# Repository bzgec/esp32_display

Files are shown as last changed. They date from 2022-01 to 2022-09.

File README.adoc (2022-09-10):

= MQTT display HW
:toc:
:sectnums:
:sectnumlevels: 4

* Current version: *0.1*
* link:./CHANGELOG.adoc[Changelog]

'''

MQTT display using:

* ESP32
* ILI9341 display

[link="./Res/pic/display_mqtt.jpg"]
.Example
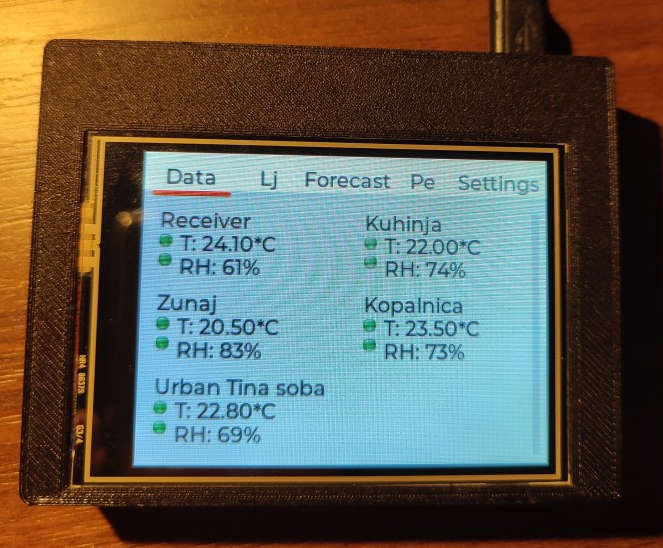
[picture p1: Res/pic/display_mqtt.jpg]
display_mqtt


== PCB:

=== v0.1

[link="./Res/pic/hw_v0.1_bottom_real.jpg"]
.HW v0.1
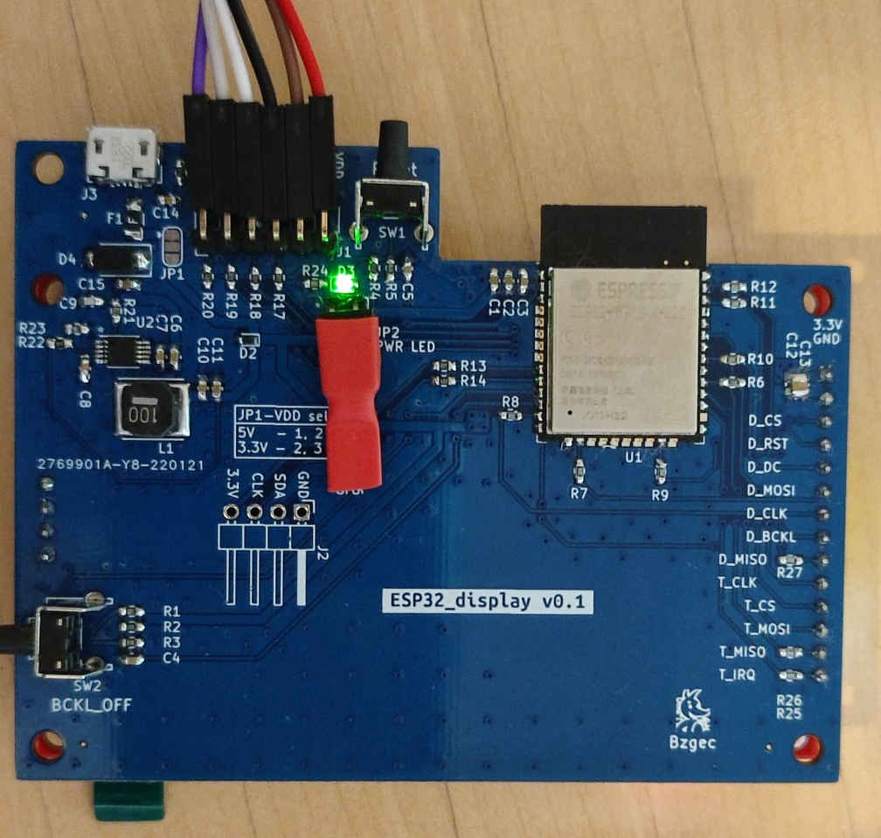
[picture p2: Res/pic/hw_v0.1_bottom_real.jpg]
hw_v0.1_bottom_real


== Automated exporting
=== Installation
==== KiBot
link:https://github.com/INTI-CMNB/kibot#installation-using-pip[Installation]:

* `pip install --no-compile kibot`
(on Windows you probably need to install it in `KiCad Command Prompt`)

* On Arch Linux you can install it with: `paru -S kibot-git`
** You may need to install `pcbdraw-git` in case of
`module 'pcbnew' has no attribute 'PLOTTEXTMODE_STROKE'` error
(try to run `pcbnew --version` to be sure that program runs correctly)
** You also may need to install `imagemagick`: `sudo pacman -S imagemagick`
** You also may need to install few `pip` packages: `pip install mistune pybars3 wand`

==== recordmydesktop
* Needed only if running `kibot -vvv`
* Arch Linux: `sudo pacman -S recordmydesktop`

== TODO
* [ ] Fix silkscreen for programming connector (TX and RX are replaced, also the same for IO0 and RST)
* [ ] Remove Display module SD card slot - that way display can seat lower
  (whole PCB if then thinner)

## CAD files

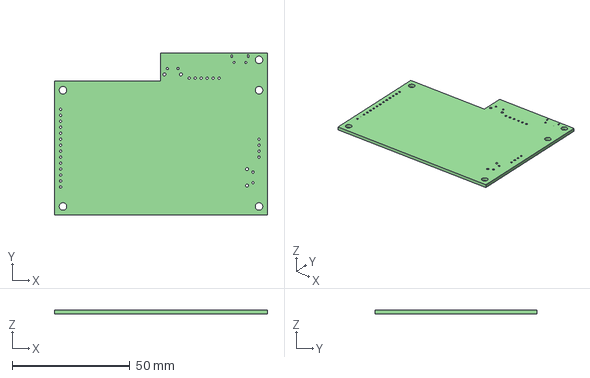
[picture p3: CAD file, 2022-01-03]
Outputs/v0.1/esp32_display.step
90.5 x 69.0 x 1.60 mm

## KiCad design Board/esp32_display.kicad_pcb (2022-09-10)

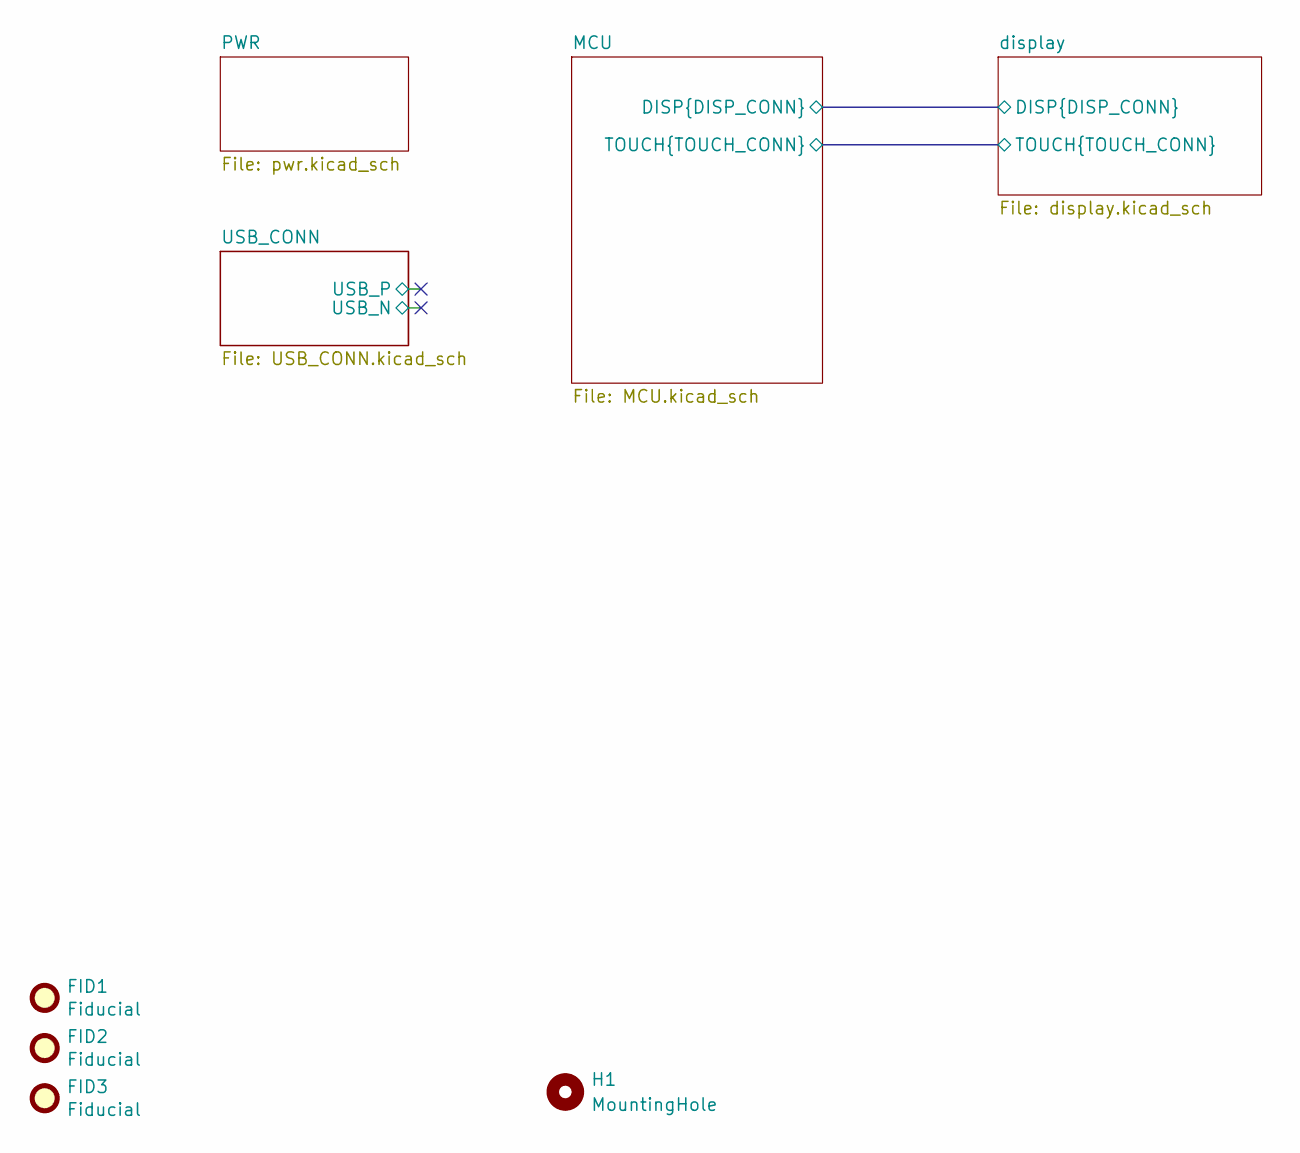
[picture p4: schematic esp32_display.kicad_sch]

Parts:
FID1, FID2, FID3: Fiducial; Fiducial_0.5mm_Mask1mm
H1: MountingHole; MountingHole_3.2mm_M3_ISO14580

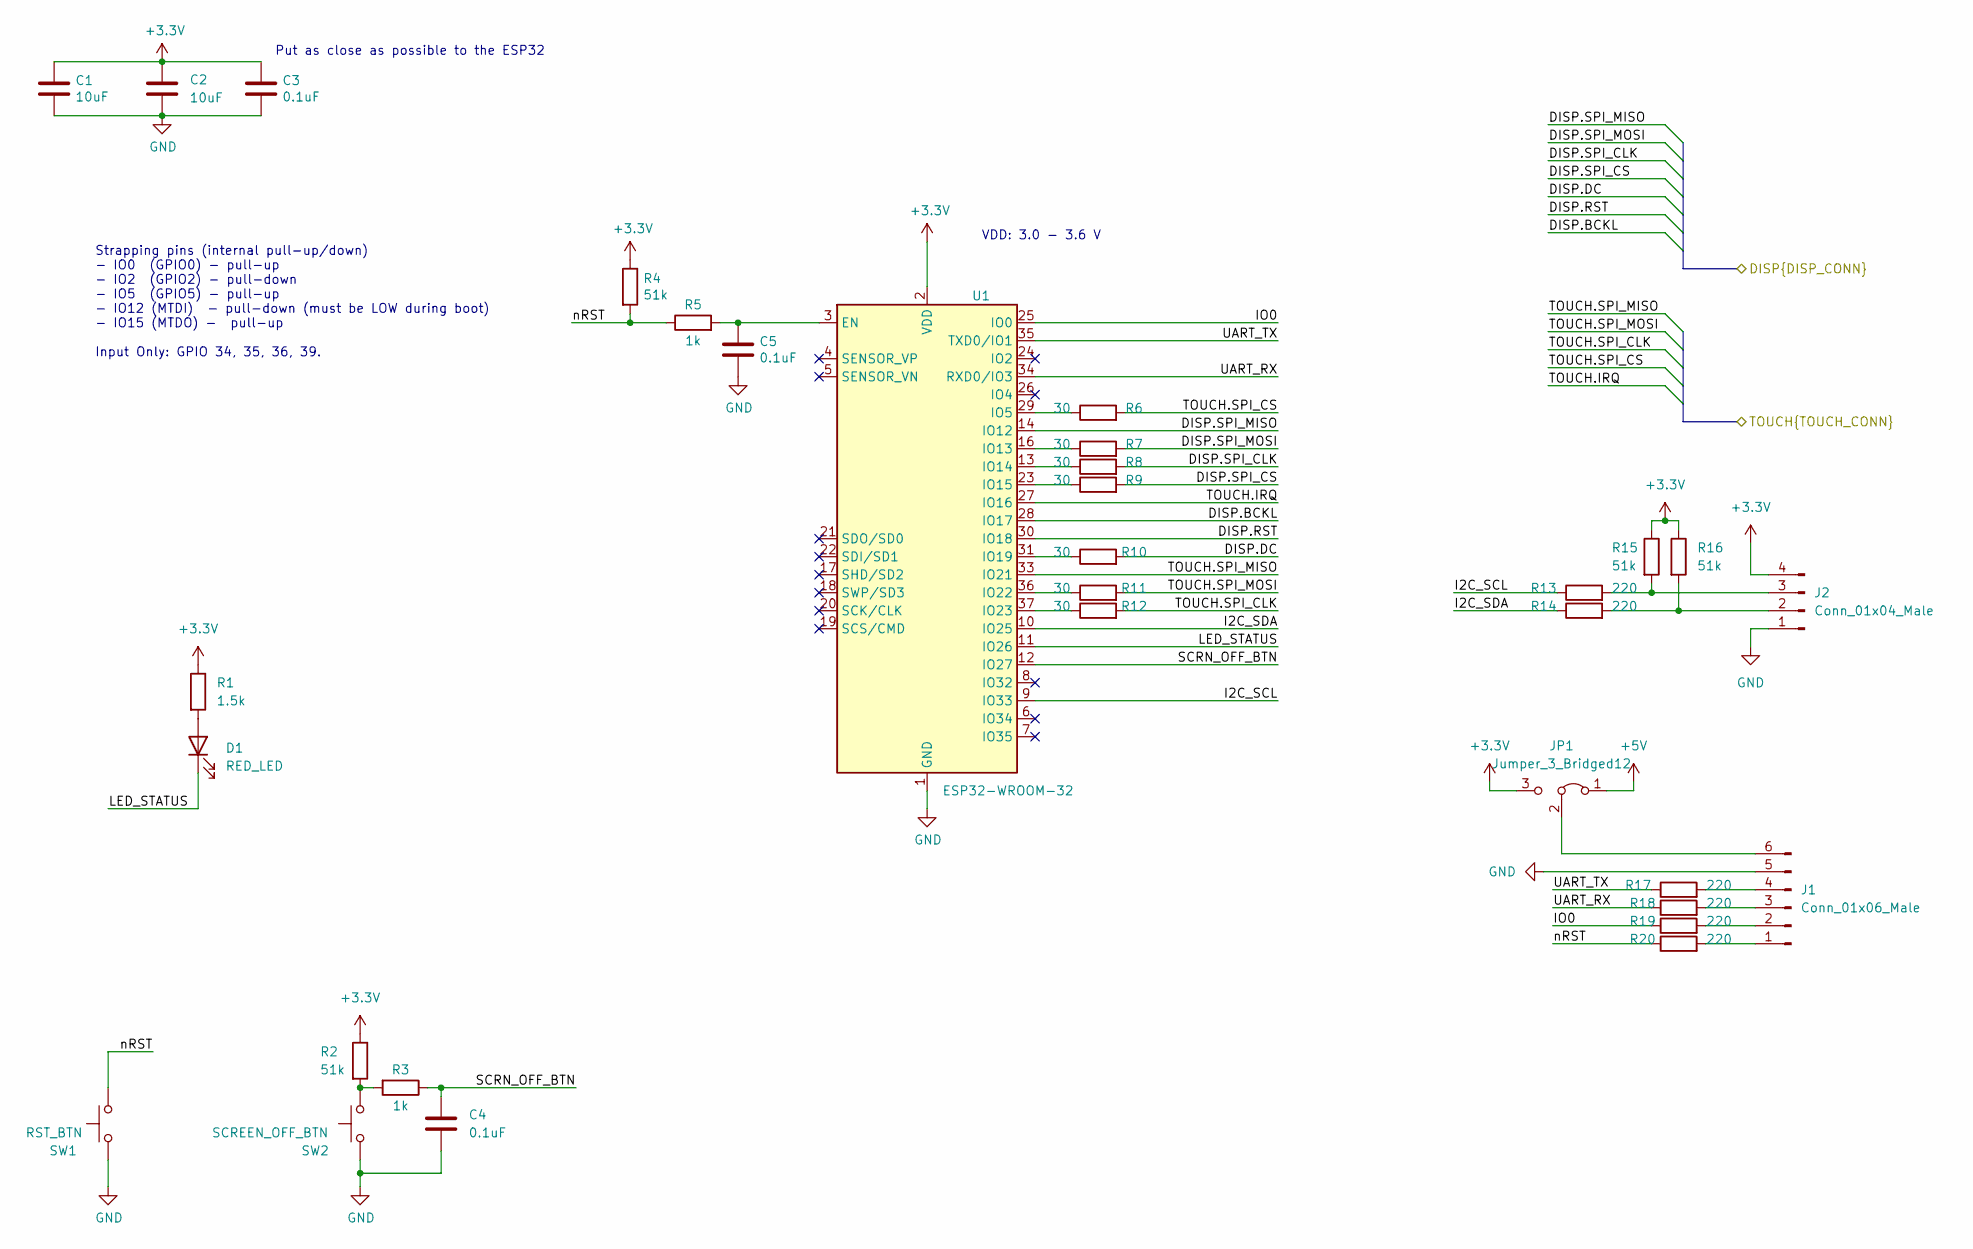
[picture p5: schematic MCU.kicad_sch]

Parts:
C1, C2: 10uF; C_0603_1608Metric_Pad1.08x0.95mm_HandSolder
C3, C4, C5: 0.1uF; C_0603_1608Metric_Pad1.08x0.95mm_HandSolder
D1: RED_LED; D_0603_1608Metric_Pad1.05x0.95mm_HandSolder
J1: Conn_01x06_Male; PinHeader_1x06_P2.54mm_Horizontal
J2: Conn_01x04_Male; PinHeader_1x04_P2.54mm_Horizontal
JP1: Jumper_3_Bridged12; SolderJumper-3_P1.3mm_Bridged12_RoundedPad1.0x1.5mm
R1: 1.5k; R_0603_1608Metric_Pad0.98x0.95mm_HandSolder
R2, R4, R15, R16: 51k; R_0603_1608Metric_Pad0.98x0.95mm_HandSolder
R3, R5: 1k; R_0603_1608Metric_Pad0.98x0.95mm_HandSolder
R6, R7, R8, R9, R10, R11, R12: 30; R_0603_1608Metric_Pad0.98x0.95mm_HandSolder
R13, R14, R17, R18, R19, R20: 220; R_0603_1608Metric_Pad0.98x0.95mm_HandSolder
SW1: RST_BTN; SW_Tactile_SPST_Angled_PTS645Vx83-2LFS
SW2: SCREEN_OFF_BTN; SW_Tactile_SPST_Angled_PTS645Vx83-2LFS
U1: ESP32-WROOM-32

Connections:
+3V3: C1.1, C2.1, C3.1, J2.4, JP1.3 (B), R1.1, R2.1, R4.1, R15.1, R16.1, U1.2 (VDD); also elsewhere on the board
+5V: JP1.1 (A); also elsewhere on the board
/MCU/DISP.BCKL: U1.28 (IO17); also elsewhere on the board
/MCU/DISP.DC: R10.2; also elsewhere on the board
/MCU/DISP.RST: U1.30 (IO18); also elsewhere on the board
/MCU/DISP.SPI_CLK: R8.2; also elsewhere on the board
/MCU/DISP.SPI_CS: R9.2; also elsewhere on the board
/MCU/DISP.SPI_MISO: U1.14 (IO12); also elsewhere on the board
/MCU/DISP.SPI_MOSI: R7.2; also elsewhere on the board
/MCU/I2C_SCL: R13.1, U1.9 (IO33)
/MCU/I2C_SDA: R14.1, U1.10 (IO25)
/MCU/IO0: R19.1, U1.25 (IO0)
/MCU/LED_STATUS: D1.1 (K), U1.11 (IO26)
/MCU/SCRN_OFF_BTN: C4.1, R3.1, U1.12 (IO27)
/MCU/TOUCH.IRQ: U1.27 (IO16); also elsewhere on the board
/MCU/TOUCH.SPI_CLK: R12.2; also elsewhere on the board
/MCU/TOUCH.SPI_CS: R6.2; also elsewhere on the board
/MCU/TOUCH.SPI_MISO: U1.33 (IO21); also elsewhere on the board
/MCU/TOUCH.SPI_MOSI: R11.2; also elsewhere on the board
/MCU/UART_RX: R18.1, U1.34 (RXD0/IO3)
/MCU/UART_TX: R17.1, U1.35 (TXD0/IO1)
/MCU/nRST: R4.2, R5.1, R20.1, SW1.1
GND: C1.2, C2.2, C3.2, C4.2, C5.2, J1.5, J2.1, SW1.2, SW2.2, U1.1 (GND), U1.15 (GND), U1.38 (GND), U1.39 (GND); also elsewhere on the board
unnamed: C5.1, R5.2, U1.3 (EN)
unnamed: D1.2 (A), R1.2
unnamed: J1.1, R20.2
unnamed: J1.2, R19.2
unnamed: J1.3, R18.2
unnamed: J1.4, R17.2
unnamed: J1.6, JP1.2 (C)
unnamed: J2.2, R14.2, R16.2
unnamed: J2.3, R13.2, R15.2
unnamed: R2.2, R3.2, SW2.1
unnamed: R6.1, U1.29 (IO5)
unnamed: R7.1, U1.16 (IO13)
unnamed: R8.1, U1.13 (IO14)
unnamed: R9.1, U1.23 (IO15)
unnamed: R10.1, U1.31 (IO19)
unnamed: R11.1, U1.36 (IO22)
unnamed: R12.1, U1.37 (IO23)

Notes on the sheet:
Put as close as possible to the ESP32
Strapping pins (internal pull-up/down) - IO0 (GPIO0) - pull-up - IO2 (GPIO2) - pull-down - IO5 (GPIO5) - pull-up - IO12 (MTDI) - pull-down (must be LOW during boot) - IO15 (MTDO) - pull-up Input Only: GPIO 34, 35, 36, 39.
VDD: 3.0 - 3.6 V

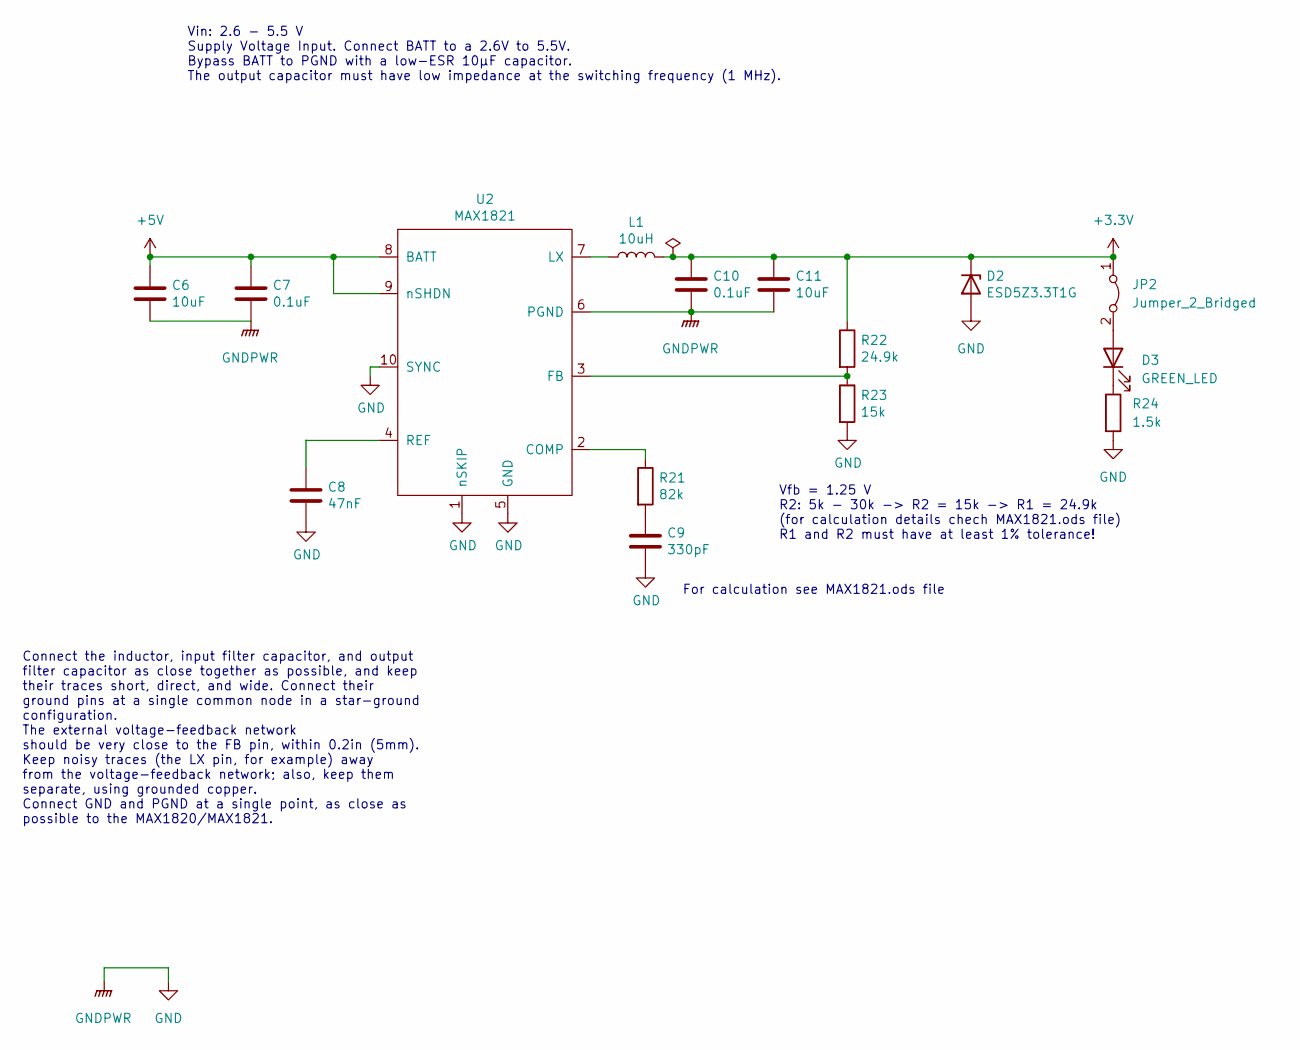
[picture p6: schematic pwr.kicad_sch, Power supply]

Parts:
C6, C11: 10uF; C_0603_1608Metric_Pad1.08x0.95mm_HandSolder
C7, C10: 0.1uF; C_0603_1608Metric_Pad1.08x0.95mm_HandSolder
C8: 47nF; C_0603_1608Metric_Pad1.08x0.95mm_HandSolder
C9: 330pF; C_0603_1608Metric_Pad1.08x0.95mm_HandSolder
D2: ESD5Z3.3T1G; D_SOD-523
D3: GREEN_LED; D_0603_1608Metric_Pad1.05x0.95mm_HandSolder
JP2: Jumper_2_Bridged; PinHeader_1x02_P2.54mm_Horizontal
L1: 10uH; NR6028T100M
R21: 82k; R_0603_1608Metric_Pad0.98x0.95mm_HandSolder
R22: 24.9k; R_0603_1608Metric_Pad0.98x0.95mm_HandSolder
R23: 15k; R_0603_1608Metric_Pad0.98x0.95mm_HandSolder
R24: 1.5k; R_0603_1608Metric_Pad0.98x0.95mm_HandSolder
U2: MAX1821; MAX1821EUB+

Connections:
+3V3: C10.1, C11.1, D2.1 (K), JP2.1 (A), L1.2, R22.1; also elsewhere on the board
+5V: C6.1, C7.1, U2.8 (BATT), U2.9 (nSHDN); also elsewhere on the board
GND: C6.2, C7.2, C8.2, C9.2, C10.2, C11.2, D2.2 (A), R23.2, R24.2, U2.1 (nSKIP), U2.5 (GND), U2.6 (PGND), U2.10 (SYNC); also elsewhere on the board
unnamed: C8.1, U2.4 (REF)
unnamed: C9.1, R21.2
unnamed: D3.1 (K), R24.1
unnamed: D3.2 (A), JP2.2 (B)
unnamed: L1.1, U2.7 (LX)
unnamed: R21.1, U2.2 (COMP)
unnamed: R22.2, R23.1, U2.3 (FB)

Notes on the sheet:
Vfb = 1.25 V R2: 5k - 30k -> R2 = 15k -> R1 = 24.9k (for calculation details chech MAX1821.ods file) R1 and R2 must have at least 1% tolerance!
For calculation see MAX1821.ods file
Connect the inductor, input filter capacitor, and output filter capacitor as close together as possible, and keep their traces short, direct, and wide. Connect their ground pins at a single common node in a star-ground configuration. The external voltage-feedback network should be very close to the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
Vin: 2.6 - 5.5 V Supply Voltage Input. Connect BATT to a 2.6V to 5.5V. Bypass BATT to PGND with a low-ESR 10μF capacitor. The output capacitor must have low impedance at the switching frequency (1 MHz).

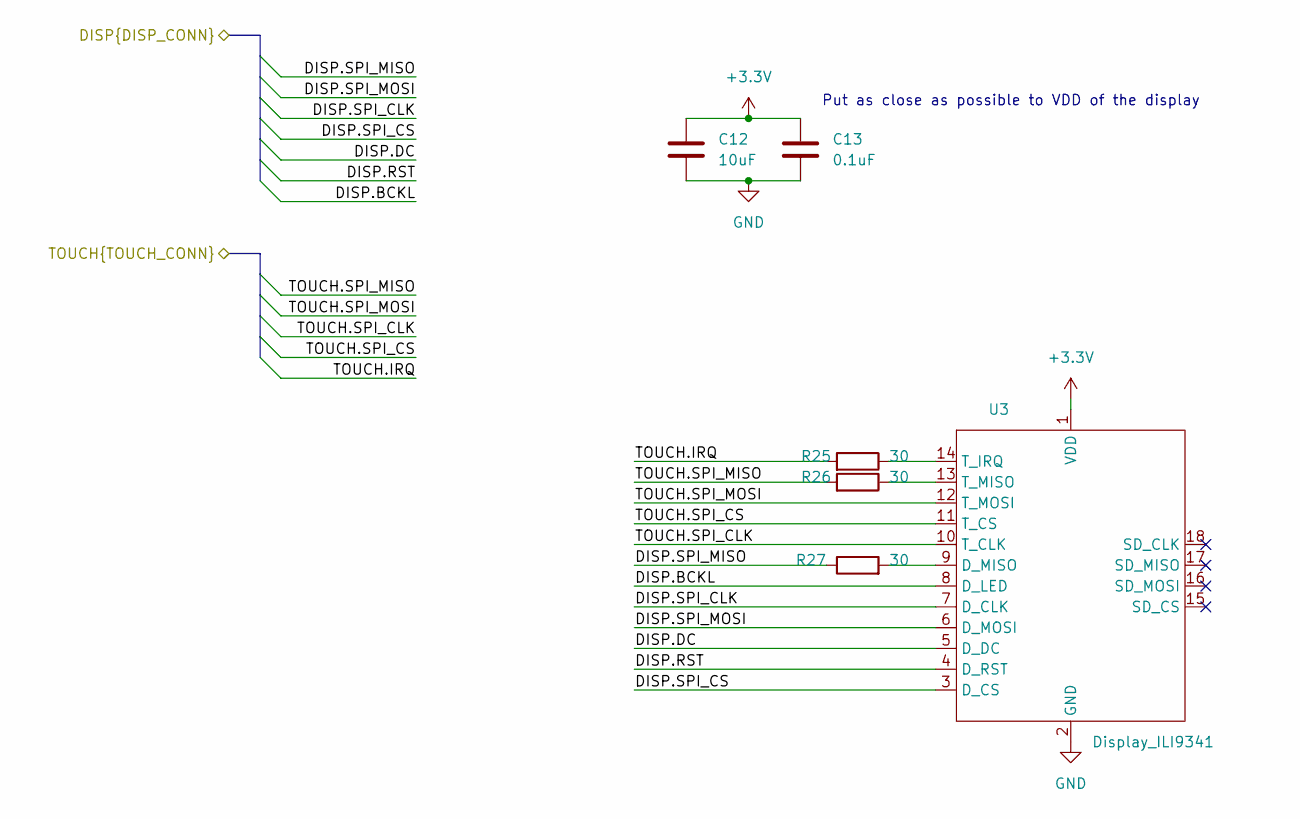
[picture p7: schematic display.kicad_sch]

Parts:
C12: 10uF; C_0603_1608Metric_Pad1.08x0.95mm_HandSolder
C13: 0.1uF; C_0603_1608Metric_Pad1.08x0.95mm_HandSolder
R25, R26, R27: 30; R_0603_1608Metric_Pad0.98x0.95mm_HandSolder
U3: Display_ILI9341; ILI9341

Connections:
+3V3: C12.1, C13.1, U3.1 (VDD); also elsewhere on the board
/MCU/DISP.BCKL: U3.8 (D_LED); also elsewhere on the board
/MCU/DISP.DC: U3.5 (D_DC); also elsewhere on the board
/MCU/DISP.RST: U3.4 (D_RST); also elsewhere on the board
/MCU/DISP.SPI_CLK: U3.7 (D_CLK); also elsewhere on the board
/MCU/DISP.SPI_CS: U3.3 (D_CS); also elsewhere on the board
/MCU/DISP.SPI_MISO: R27.1; also elsewhere on the board
/MCU/DISP.SPI_MOSI: U3.6 (D_MOSI); also elsewhere on the board
/MCU/TOUCH.IRQ: R25.2; also elsewhere on the board
/MCU/TOUCH.SPI_CLK: U3.10 (T_CLK); also elsewhere on the board
/MCU/TOUCH.SPI_CS: U3.11 (T_CS); also elsewhere on the board
/MCU/TOUCH.SPI_MISO: R26.2; also elsewhere on the board
/MCU/TOUCH.SPI_MOSI: U3.12 (T_MOSI); also elsewhere on the board
GND: C12.2, C13.2, U3.2 (GND); also elsewhere on the board
unnamed: R25.1, U3.14 (T_IRQ)
unnamed: R26.1, U3.13 (T_MISO)
unnamed: R27.2, U3.9 (D_MISO)

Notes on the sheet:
Put as close as possible to VDD of the display

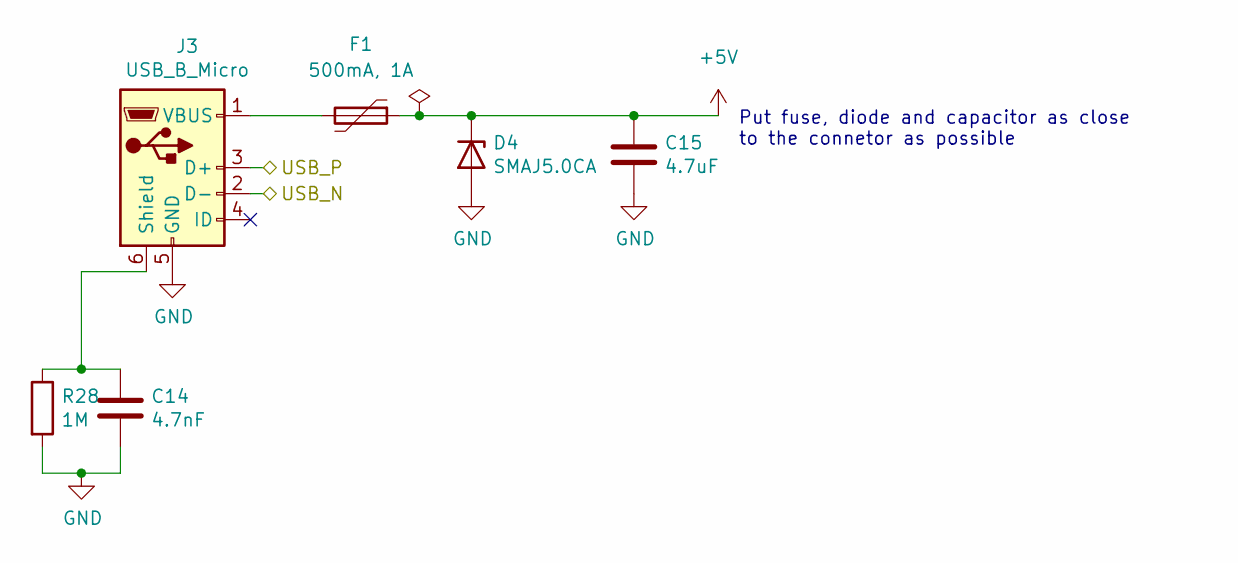
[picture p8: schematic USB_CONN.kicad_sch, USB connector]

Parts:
C14: 4.7nF; C_0603_1608Metric_Pad1.08x0.95mm_HandSolder
C15: 4.7uF; C_0603_1608Metric_Pad1.08x0.95mm_HandSolder
D4: SMAJ5.0CA; D_SMA
F1: 500mA, 1A; Fuse_1206_3216Metric_Pad1.42x1.75mm_HandSolder
J3: USB_B_Micro; USB_Micro-B_Molex-105017-0001
R28: 1M; R_0603_1608Metric_Pad0.98x0.95mm_HandSolder

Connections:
+5V: C15.1, D4.1 (K), F1.1; also elsewhere on the board
/USB_CONN/USB_N: J3.2 (D-)
/USB_CONN/USB_P: J3.3 (D+)
GND: C14.2, C15.2, D4.2 (A), J3.5 (GND), R28.2; also elsewhere on the board
unnamed: C14.1, J3.6 (Shield), R28.1
unnamed: F1.2, J3.1 (VBUS)

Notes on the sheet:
Put fuse, diode and capacitor as close to the connetor as possible

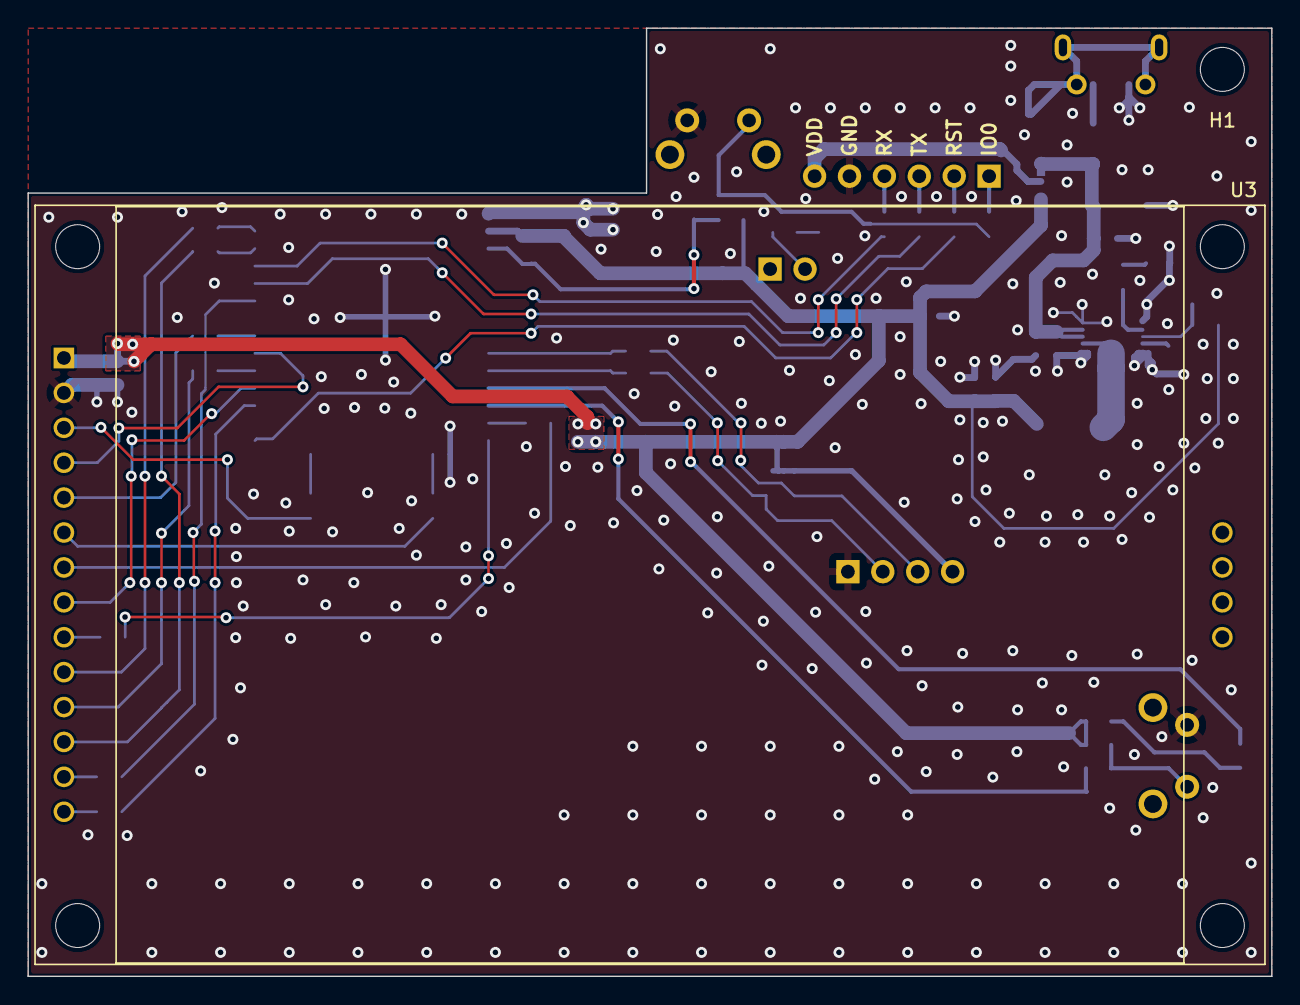
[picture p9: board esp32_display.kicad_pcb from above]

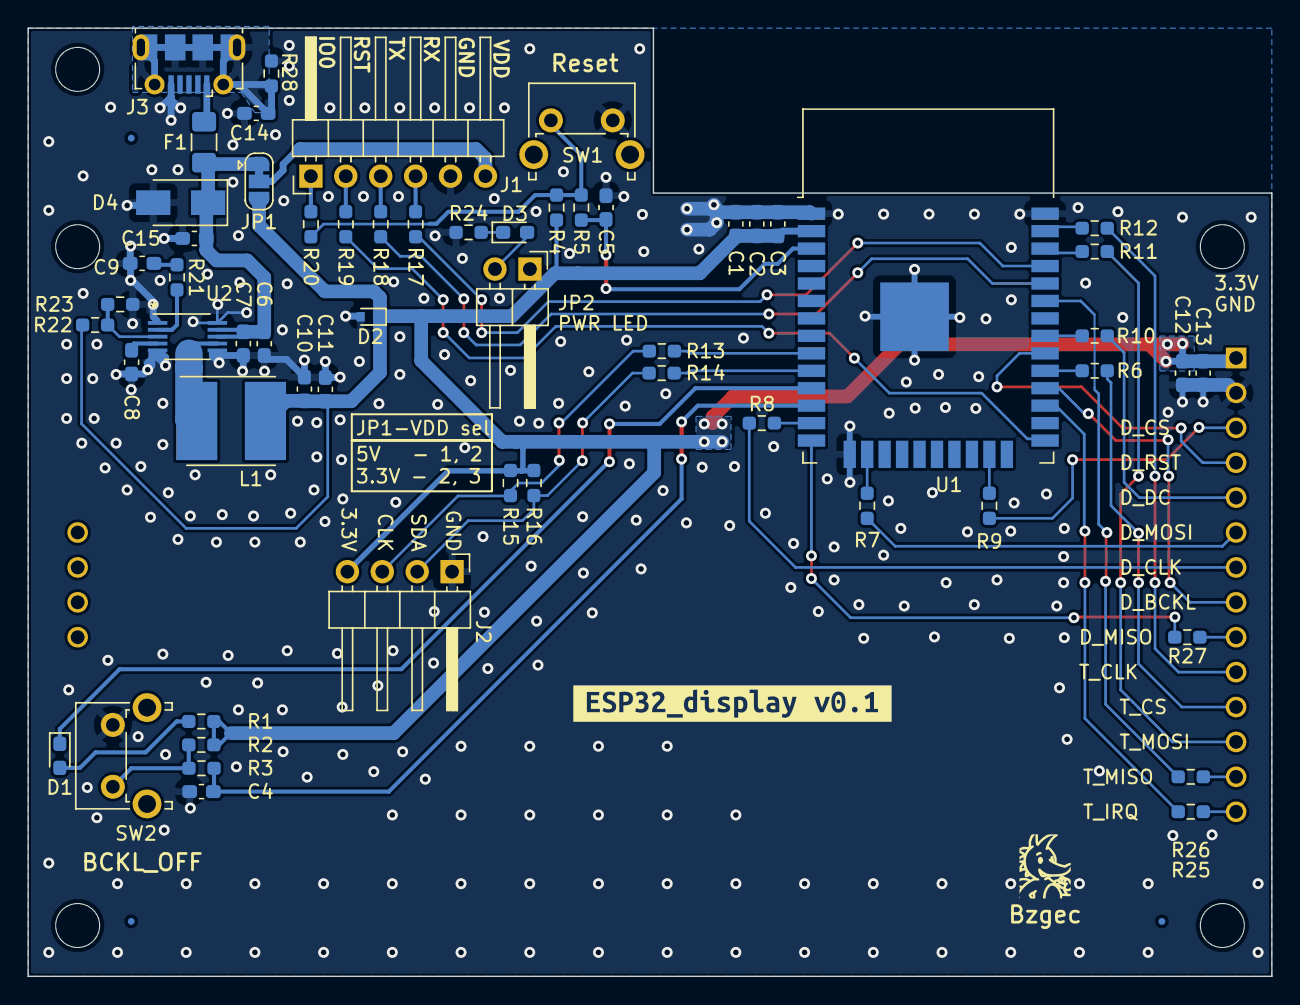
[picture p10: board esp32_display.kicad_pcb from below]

Board: 2 copper layers, 90.5 x 69.0 mm, 64 parts (62 on the bottom side), 52 nets.

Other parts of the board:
kibuzzard-61D6E91A: G***; kibuzzard-61D6E91A

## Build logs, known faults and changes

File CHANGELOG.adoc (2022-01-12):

= ESP32_display HW
:toc:

== v0.1 - 2022/01/00
=== Added
=== Changed
=== Fixed
=== Removed

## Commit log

2021-12-30 Add housing edge, generate output files
    [MCU.kicad_sch, esp32_display.kicad_pcb, esp32_display.kicad_sch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]
2022-01-03 Smaller footprint, no housing, right angle buttons
    [MCU.kicad_sch, esp32_display.kicad_pcb, esp32_display.kicad_sch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]
2022-01-04 Add serial resistors to SPI lines (PCB not finished)
    Still missing placment of RC filters.
    [MCU.kicad_sch, display.kicad_sch, esp32_display.kicad_pcb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]
2022-01-04 Rename TVS/ESD protection diodes to their name (5V and 3.3V)
    [esp32_display.kicad_pcb, esp32_display.kicad_sch]
2022-01-04 Add square around PCB name and verion
    [esp32_display.kicad_pcb]
2022-01-05 Place RC filters (close to buttons)
    [esp32_display.kicad_pcb]
2022-01-05 Dont route L of buck converter through vias
    [esp32_display.kicad_pcb]
2022-01-05 Fix 3d models, generate outputs, add .wrl to outputs
    [esp32_display.kicad_pcb, esp32_display.kicad_sch]
2022-01-06 Fix myLib footprint path (from absolute to relative)
2022-01-06 Buck converter feedback line on top
    PCB name and version generated with KiBuzzard
    [esp32_display.kicad_pcb]
2022-01-06 Move from PCB/v0.1/esp32_display to Board/v0.1
    [MCU.kicad_sch, display.kicad_sch, esp32_display.kicad_pcb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]
2022-01-06 Fix board -> Board
    [MCU.kicad_sch, display.kicad_sch, esp32_display.kicad_pcb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]
2022-01-06 Clean schematics (add date and revision...)
    [MCU.kicad_sch, display.kicad_sch, esp32_display.kicad_pcb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]
2022-01-06 Move ".kibot.yaml" to Board... folder
2022-01-07 Add polyfuse, 3.3V status LED, USB_CONN sheet
    [MCU.kicad_sch, USB_CONN.kicad_sch, display.kicad_sch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]
2022-01-07 Fix missing pad for H1, fix missing power input ERC error
    ERC error was: Input power pin not driven by any output power pins.
    Fix was adding PWR_FLAG power symbol after polyfuse or inductor.
    [MCU.kicad_sch, USB_CONN.kicad_sch, display.kicad_sch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]
2022-01-07 Add KiBot DRC filters
    [esp32_display.kicad_pcb]
2022-01-07 Generate gerbers, sch and BOM with KiBot
    [USB_CONN.kicad_sch, esp32_display.kicad_pcb, esp32_display.kicad_sch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]
2022-01-07 Try to implement pcbdraw
2022-01-07 Working pcbdraw - generating *_pcbdraw_*.jpg
2022-01-07 Try to implement .step export
    [esp32_display.step]
2022-01-08 Fix some via position, chane Net-(J1-Pad6) trace width
    [esp32_display.kicad_pcb]
2022-01-09 Add ILI9341 3D model, change few via positions
    [esp32_display.kicad_pcb]
2022-01-09 Fix ILI9341 display symbol (pin numbering)
    [MCU.kicad_sch, display.kicad_sch, esp32_display.kicad_pcb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]
2022-01-10 Add jumper for 3.3V power LED
    [esp32_display.kicad_pcb, esp32_display.kicad_sch, pwr.kicad_sch]
2022-01-10 Add info about ESP32 strapping pins
    [MCU.kicad_sch]
2022-01-12 Move Board/v0.1 to Board, move kicadLib to Board/kicadLib, remove Outputs
    [MCU.kicad_sch, USB_CONN.kicad_sch, display.kicad_sch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]
2022-01-14 Add I2C pin header
    [MCU.kicad_sch, USB_CONN.kicad_sch, display.kicad_sch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]
2022-01-17 Fix USB silkscreen over board warning, other minimal fixes
    [MCU.kicad_sch, USB_CONN.kicad_sch, display.kicad_sch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]
2022-01-18 Add fiducials
    [MCU.kicad_sch, USB_CONN.kicad_sch, display.kicad_sch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]
2022-01-18 Add dpi option for pcbdraw in .kibot.yaml
2022-01-19 Add Paste layer to JLCPCB gerber config
2022-01-20 Fix buck inductor (uF -> uH)
    [esp32_display.kicad_sch, pwr.kicad_sch]
2022-09-10 Update typo
    [esp32_display.kicad_pcb, esp32_display.kicad_sch, pwr.kicad_sch]

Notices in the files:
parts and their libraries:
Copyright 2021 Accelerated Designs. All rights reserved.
